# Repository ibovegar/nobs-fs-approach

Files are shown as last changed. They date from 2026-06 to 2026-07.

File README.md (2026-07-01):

# Nobs Approach

A build-it-yourself lever panel for flight simulators: **3 levers** (Flaps, Gear, Parking Brake)
wired to an **Arduino Nano ESP32**. It plugs in over USB and shows up as a standard game controller
(HID gamepad) named **"Nobs Approach"**, recognised directly by MSFS and the Nobs app with no
drivers to install.

All three levers are 3-position (ON-OFF-ON); each lever's two outer positions are reported as two
buttons, for **6 buttons** total.

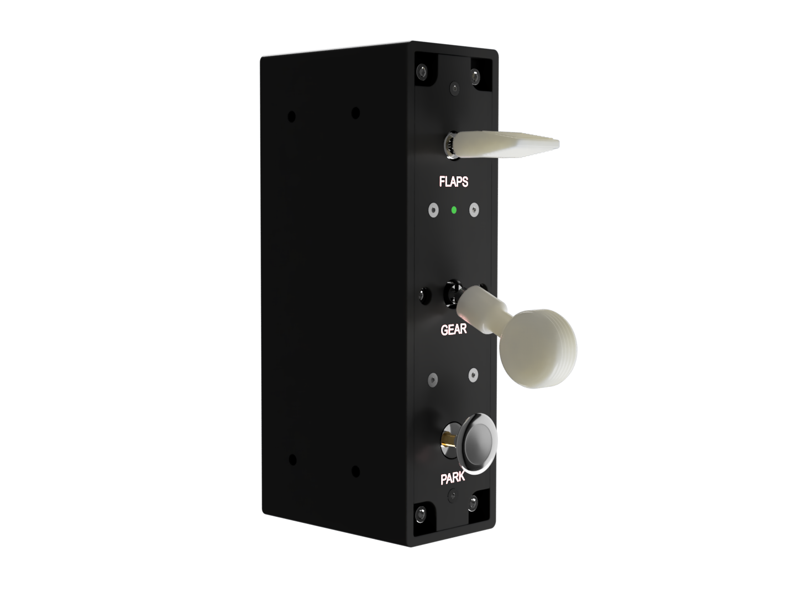
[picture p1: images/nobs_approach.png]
Nobs Approach


## Docs

- **[Which wire goes where](docs/arduino-esp-32-wiring.md)**: the button + pin map. For a visual
  reference alongside it, see the [wiring diagram](docs/wiring-diagram.pdf).
- **[Loading the firmware](firmware/arduino_eps32_nano/README.md)**: first-time flashing and
  re-flashing, step by step.
- **[Setting the device ID & name](docs/board-identity.md)**: how the board names itself, how to
  rename it, and how to run several approach panels at once (each gets its own ID + name).
- **[Bill of materials](docs/bill-of-materials.md)**: parts list.

## Nobs FS Companion App

The [**Nobs FS app**](https://github.com/ibovegar/nobs-fs-app) is the companion application for
communicating with and configuring this panel. It automatically detects the Nobs Approach by its
USB identity (VID `303A` / PID `80F8`), so the right device is selected even when other game
controllers are connected.

Use it to:
* **Verify wiring & test inputs:** watch every lever position register live as you move it, handy
  for confirming the build before binding anything in the sim.
* **Track multiple approach panels:** the Devices page lets you add extra instances of the panel,
  each with its own ID and name (see [Setting the device ID & name](#setting-the-device-id--name-in-brief)
  below), so the app and the sim can tell them apart.

See the app repository for installation and usage details: <https://github.com/ibovegar/nobs-fs-app>

## Setting the device ID & name (in brief)

The board's name and USB product ID aren't compiled in; they're stored on the board, so the same
firmware can be set up as any Nobs profile. Out of the box this is **"Nobs Approach"** (`303A` /
`80F8`). To change it, the configuration app sends a single line over the board's serial port:

```
SET_ID:80F8:Nobs Approach
```

The board saves the new name + ID, replies `OK:80F8:Nobs Approach`, and reboots so it takes effect
(`GET_ID` reads back the current values). For multiple approach panels, give each one the next ID in
the block, e.g. `SET_ID:80F9:Nobs Approach 2`. Full details, including the Windows name-cache
refresh, are in **[docs/board-identity.md](docs/board-identity.md)**.

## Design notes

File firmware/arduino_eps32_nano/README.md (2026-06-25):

# Nobs Approach: Arduino Nano ESP32 Firmware

This is the program (the "firmware") that runs on an **Arduino Nano ESP32** and turns it into a USB
game controller for Microsoft Flight Simulator. Once loaded, the board shows up to your PC and the
Nobs app as **"Nobs Approach"** with **6 buttons**: the 3 levers (Flaps, Gear, Parking Brake), two
buttons each (one per position). Wiring is in
[`docs/arduino-esp-32-wiring.md`](../../docs/arduino-esp-32-wiring.md).

All three levers are **ON-OFF-ON** (3-position): one outer position presses the first button, the
other presses the second, and the center position presses neither.

> 👍 Everything you need is in this folder. You don't edit any Arduino files. Keep
> [`build_opt.h`](./build_opt.h) next to the sketch: the IDE uses it automatically, and the build
> fails on purpose without it. Tested with the Arduino ESP32 board package `2.0.18-arduino.5`.

## One-time setup

1. Install the **Arduino IDE** (free, from arduino.cc).
2. Add the board: **Tools → Board → Boards Manager…**, search **Arduino ESP32 Boards**, click
   **Install** (big download). Then pick **Tools → Board → Arduino ESP32 Boards → Arduino Nano ESP32**.
3. In **Tools**, set **USB Mode → `Normal mode (TinyUSB)`** and **Pin Numbering → `By Arduino pin (default)`**.

> If the board install fails ("platform not installed"), close the IDE, reopen it **as
> administrator**, and try again.

## Flashing the first time

1. Open [`arduino_eps32_nano.ino`](./arduino_eps32_nano.ino) in the Arduino IDE.
2. Plug in the board with a **data** USB cable (not charge-only), straight into the PC.
3. Click **Upload** (the round arrow).

On a fresh board this just works. 🎉 When it's done, the board reconnects as **"Nobs Approach"** and
the app picks it up automatically.

## Re-flashing (after firmware is already on it)

This is **different**, and expected. Once the firmware is running, the board reports a custom USB
ID and no longer auto-enters upload mode, so a normal Upload fails with:

```
No DFU capable USB device available — exit status 74
```

Put the board into **update mode** by hand first:

1. Press the **RESET** button **twice, quickly** (like a mouse double-click, ~0.3–0.5 s apart).
2. You're in update mode when the **green LED breathes slowly in and out and stays there**.
   A quick red→blue→green flash that stops is just a normal reset; try the double-tap again.
3. With the green breathing, click **Upload** right away.
4. When it finishes, press **RESET once** to start the firmware.

> **If upload still can't find the board:** it's almost always the **cable or USB port**; swap to
> a known-good data cable and a different port (this is the most common cause). The double-tap
> timing is the other one; keep trying the rhythm.

## Check it works

- **Nobs app:** the approach panel is detected automatically; move the levers and watch them react.
- **Windows:** press `Win`, type **Set up USB game controllers**, open the device's **Properties**,
  and move the levers to see the 6 buttons react.

## Changing the board's name / ID

The name and product ID aren't compiled in; they're stored on the board, so the same firmware can
become any Nobs profile. Out of the box it's **"Nobs Approach"** (`303A` / `80F8`). The configuration
app changes it over the board's serial port. See
[`docs/board-identity.md`](../../docs/board-identity.md) for how that works and the full profile list.

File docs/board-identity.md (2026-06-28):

# How the Board Names Itself (and How to Rename It)

This page explains, in plain language, how a Nobs board tells your PC who it is, and how you can
change that without re-installing the firmware. You don't need to understand any of this to use the
approach panel; it's here for the curious and for anyone setting up more than one box.

## The short version

- Every Nobs box appears to your PC as a USB game controller with a **name** (like "Nobs Approach")
  and an **ID number** (called a *Product ID*, or **PID**).
- That name and ID are **not baked into the firmware**. The board remembers them in its own memory,
  so the *same* firmware can be set up as a panel, an autopilot, or an approach box.
- Out of the box, this board is **"Nobs Approach"**. You can change it later with the configuration
  app, no re-flashing needed.

## Why each box needs its own name and ID

If you own more than one Nobs box, this matters. Microsoft Flight Simulator keeps a separate set of
button bindings for each controller, but it tells controllers apart by their **ID number**.

If two boxes shared the same ID, the simulator would treat them as the same device and **mix up
their button assignments**. Giving each box its own ID (and a clear name) keeps their controls
neatly separated, so plugging in a second or third box never disturbs the first.

Here are the standard profiles. Each product owns a small **block of IDs** so you can have several
of the same type (see below):

| If the box is a… | It should be named… | ID block |
| :--- | :--- | :--- |
| Panel | Nobs Panel | `80F0`–`80F3` |
| Autopilot | Nobs Autopilot | `80F4`–`80F7` |
| Approach | Nobs Approach | `80F8`–`80FB` |

(They all share the same *vendor* ID, `303A`; that part never changes.)

## Running several of the same type

You can use more than one of the same module, say two approach panels, at the same time. The
catch is they must **not** look identical to the PC, or the simulator mixes up their bindings. So
each one gets its own ID and name from its product's block:

| | Name | ID |
| :-- | :-- | :-- |
| 1st approach | Nobs Approach | `80F8` |
| 2nd approach | Nobs Approach 2 | `80F9` |
| 3rd approach | Nobs Approach 3 | `80FA` |

The first one keeps the plain name and the block's first ID (its out-of-box default). For each
extra one, give it the next ID and a numbered name with the rename step below: e.g. send
`SET_ID:80F9:Nobs Approach 2` to the second one. In the Nobs app, open **Devices** and press **+**
on that product to start tracking the extra module. The simulator then sees "Nobs Approach" and
"Nobs Approach 2" as two separate controllers with independent bindings.

## How to rename a board

The configuration app does this for you. Behind the scenes it just sends the board one short line of
text over its connection, for example:

```
SET_ID:80F8:Nobs Approach
```

That reads as: *"Set your ID to `80F8` and your name to `Nobs Approach`."* The board then:

1. **Saves** the new name and ID into its own memory.
2. **Confirms** it received them.
3. **Restarts itself**, and comes back wearing the new name.

That restart is normal and only takes a second. The reason it's needed: a board can only announce
its identity to the PC at the moment it powers on, so it has to reboot for a new name to take effect.

> 💡 To check what a board is currently called, the app can ask it with `GET_ID`, and the board
> replies with its stored name and ID. The board also announces its name and ID on its own, the
> moment the app connects — so the app doesn't even need to ask.

## If Windows still shows the old name

Windows likes to remember names, so occasionally after a rename it'll keep showing the **old** one
in its game-controller list or in the simulator. If that happens, nudge it to take a fresh look:

1. Leave the board plugged in.
2. Right-click the **Start** button → open **Device Manager**.
3. Open the **Human Interface Devices** group.
4. Right-click your controller → **Uninstall device**.
5. Unplug the USB cable, wait a couple of seconds, and plug it back in.

Windows will then read the board's name again from scratch and show the updated one.

## Related pages

- [Which wire goes where](./arduino-esp-32-wiring.md): the button and pin map.
- [Loading the firmware](../firmware/arduino_eps32_nano/README.md): step-by-step setup, including
  the more technical details of how the identity is stored.

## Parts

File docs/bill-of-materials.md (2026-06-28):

# Bill of Materials (Shopping List)

This is the full shopping list for building one Nobs Approach panel: every part you need, from the
electronics to the screws. The "Manufacturer / Part Number" column lists the exact parts we used,
linked to their Mouser listing, so you can search for them or find equivalents.

A few friendly notes before you start buying:

- **Exact parts aren't mandatory.** Most components can be swapped for similar parts you like or
  already have. The part numbers here are just what's known to work.
- **The enclosure and lever parts are 3D printed**: you print them yourself from the files in the
  `models/` folder, or have a print service make them.
- Quantities are for **one** panel.

## Core Electronics & Switches

| Item # | Qty | Component Description | Manufacturer / Part Number | Purpose / Application |
| :--- | :--- | :--- | :--- | :--- |
| **1.1** | 1 | Arduino Nano ESP32 (with headers) | [Arduino / ABX00083](https://no.mouser.com/ProductDetail/Arduino/ABX00083) | Main microcontroller (ESP32-S3, USB HID, VID 0x303A / PID 0x80F8) |
| **1.2** | 1 | SPDT Toggle Switch, Locking Lever, On-On (2-position), 15 A @ 125 VAC | [NKK Switches / S2AL](https://no.mouser.com/ProductDetail/NKK-Switches/S2AL?qs=EIJ16CYJdOsFNpXA4HNUoQ%3D%3D) | Gear lever, under `models/gear_lever.step` |
| **1.3** | 1 | SPDT Toggle Switch, Momentary (On)-Off-(On), 15 A @ 125 VAC | [Apem / 637H-2](https://no.mouser.com/ProductDetail/Apem/637H-2?qs=sGAEpiMZZMtFyPk3yBMYYM4hYjBerRHjpwkY%2FkVx7u8%3D) | Flaps lever, under `models/flaps_lever_top.step` + `flaps_lever_bottom.step` |
| **1.4** | 1 | SPDT Push-Pull Switch, On-On (2-position), Marine Grade, 10 A @ 12 VDC | [Cole Hersee / M-630](https://no.mouser.com/ProductDetail/Cole-Hersee/M-630?qs=lYH8mLnNY3r10KRvj4ytOg%3D%3D) | Parking brake lever, under `models/gear_lever.step` (shared shape) |
| **1.5** | 1 | Stripboard, 50 × 80 mm | [BusBoard Prototype Systems / ST1](https://no.mouser.com/ProductDetail/BusBoard-Prototype-Systems/ST1) | Controller board carrier for the Arduino, pin headers, and terminal block |
| **1.6** | 2 | Female Pin Header Socket, 26-position, 2.54 mm pitch | [3M Electronic Solutions Division / 929850-01-26-RA](https://no.mouser.com/ProductDetail/3M-Electronic-Solutions-Division/929850-01-26-RA) | Sockets soldered to the stripboard to seat the Arduino Nano ESP32 |
| **1.7** | 1 | Fixed Terminal Block, 6-position, 2.54 mm pitch | [GCT / TBC05-06-1-G-G](https://no.mouser.com/ProductDetail/GCT/TBC05-06-1-G-G) | Screw-down wiring for the 6 lever signal terminals (Flaps/Gear/Brake Pin 1 + Pin 3); the lever ground returns bus directly to the stripboard's GND rail |
| **1.8** | 1 | 3 mm Green LED, Diffused, 2.2 V | [Lumex / SSL-LX30FT4GD](https://no.mouser.com/ProductDetail/Lumex/SSL-LX30FT4GD?qs=7jmq9uQgtYG4HR2h%252BlgbMw%3D%3D) | Status indicator (blinks while booting/waiting for USB enumeration, steady once connected) — wired to D4 |
| **1.9** | 1 | 120 Ω Resistor, 1/4 W, ±1%, Metal Film | [KOA Speer / MFS1/4DCT52R1200F](https://no.mouser.com/ProductDetail/KOA-Speer/MFS1-4DCT52R1200F?qs=ddCg%252BR5cWn20oJHZLuYO%2FQ%3D%3D) | Current-limiting resistor for the status LED |

## Structural & Enclosure Hardware

| Item # | Qty | Component Description | Manufacturer / Part Number | Purpose / Application |
| :--- | :--- | :--- | :--- | :--- |
| **2.1** | 1 | Enclosure Top | 3D Printed (`models/enclosure_top.step`) | Main upper housing shell |
| **2.2** | 1 | Enclosure Bottom | 3D Printed (`models/enclosure_bottom.step`) | Main lower housing base, carries the controller board |
| **2.3** | 1 | Mounting Plate | 3D Printed (`models/nobs_approach_mounting_plate.step`) | Carries the 3 levers |
| **2.4** | 1 | Front Plate | 3D Printed (`models/nobs_approach_frontpanel.step`) | Visual faceplate with lever labels |
| **2.5** | 1 | Flaps Lever, Top | 3D Printed (`models/flaps_lever_top.step`) | Upper half of the Flaps lever assembly |
| **2.6** | 1 | Flaps Lever, Bottom | 3D Printed (`models/flaps_lever_bottom.step`) | Lower half of the Flaps lever assembly |
| **2.7** | 2 | Gear / Parking Brake Lever | 3D Printed (`models/gear_lever.step`) | Shared lever shape, printed once for Gear and once for Parking Brake |
| **2.8** | 10 | M4 Heat-Set Insert | [SI (PennEngineering) / IUTB-M4](https://no.mouser.com/ProductDetail/SI/IUTB-M4) | Threaded anchors moulded into the enclosure top/bottom |
| **2.9** | 10 | M3 Heat-Set Insert | [SI (PennEngineering) / IUTB-M3](https://no.mouser.com/ProductDetail/SI/IUTB-M3) | Threaded anchors moulded into the mounting plate and front plate |
| **2.10** | 4 | M4 × 0.7, 30 mm Socket-Head Screw | — | Clamps the enclosure top and bottom halves together |
| **2.11** | 6 | M4 × 0.7, 10 mm Socket-Head Screw | — | Fastens the mounting plate to the rear of the enclosure bottom |
| **2.12** | 4 | M3 × 0.5, 8 mm Pan-Head Screw | — | Fastens the controller board to its standoffs in the enclosure bottom |
| **2.13** | 6 | M3 × 0.5, 8 mm Countersunk Screw | — | Fastens the front plate to the mounting plate, and the assembly to the enclosure |

## Connectors & Wiring

| Item # | Qty | Component Description | Manufacturer / Part Number | Purpose / Application |
| :--- | :--- | :--- | :--- | :--- |
| **3.1** | 1 | USB-C to USB-A Cable, 1.5 m to 2 m, data-sync capable | — | Connects the Arduino Nano ESP32 to your PC |
| **3.2** | 1 | Heat Shrink Tubing Assortment Pack, 1.5 mm to 3.5 mm diameters | — | Insulates soldered connections on the lever terminals |

> **A note on the fastener counts above:** `enclosure_top.step`/`enclosure_bottom.step` in this
> project are geometrically identical to the panel project's, and the mounting-plate/front-plate
> *joining* holes (the ones that bolt the plates together and to the enclosure) match too — only
> the switch/lever cutouts differ, which is expected since this panel has 3 levers instead of 8
> switches. So items 2.8–2.13 are carried over directly from the panel BOM. Still worth a quick
> visual check against the printed parts before ordering, since this wasn't measured by hand.

## Project Costs

Rough cost estimate for a single panel, in USD. These are ballpark figures only, actual prices
vary significantly by supplier, region, and quantity, and **exclude shipping and taxes**. Several
items (heat-set inserts, screws) are sold in multi-build packs, so the per-build cost is lower if
you build more than one or already have them on hand.

| Category | Items | Estimated Cost |
| :--- | :--- | ---: |
| Microcontroller | Arduino Nano ESP32 (genuine; clones are cheaper) | $20 – $28 |
| Levers (switches) | NKK S2AL toggle + Apem 637H-2 + Cole Hersee M-630 | $30 – $55 |
| Board & connectors | Stripboard, 2 × pin headers, terminal block, status LED + resistor | $10 – $15 |
| Fasteners | Heat-set inserts (20) and M3/M4 screws (20) | $10 – $18 |
| Enclosure (3D printed) | Filament for top, bottom, mounting plate, front plate, and 3 levers | $5 – $15 |
| Connectors & wiring | USB-C cable, heat-shrink tubing pack | $8 – $15 |
| **Total** | | **≈ $83 – $146** |

> **Notes:**
> * The **enclosure** assumes you print the parts yourself (filament cost only). Ordering them
>   from a print service will add roughly $20 – $50.
> * This estimate doesn't include hookup wire, since it's usually bought once in bulk and reused
>   across builds.
> * Bulk/pack purchasing of the inserts, screws, and heat-shrink tubing spreads their cost across
>   multiple builds, lowering the effective per-panel total.

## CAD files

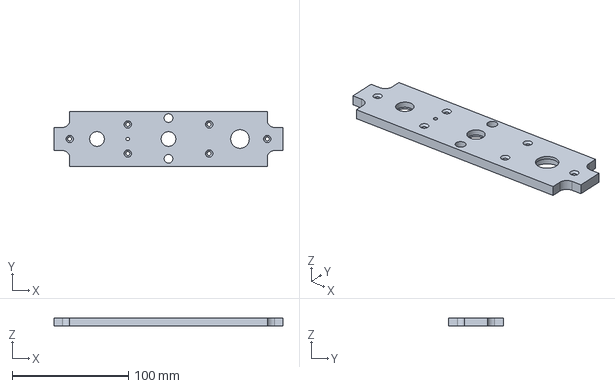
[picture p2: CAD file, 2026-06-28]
models/nobs_approach_frontpanel.step
197.0 x 47.0 x 7.00 mm

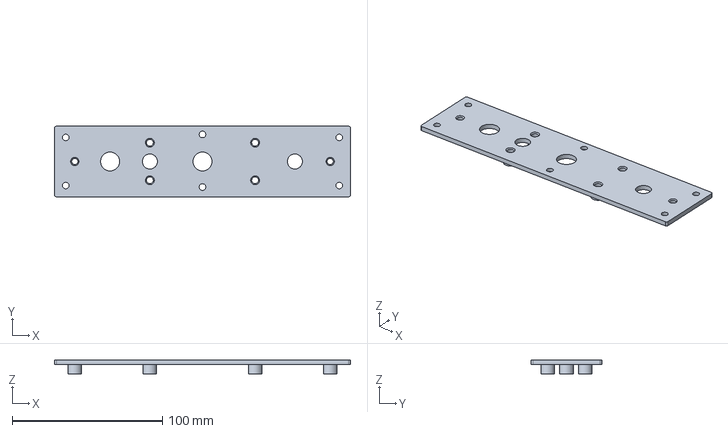
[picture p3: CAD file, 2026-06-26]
models/nobs_approach_mounting_plate.step
197.0 x 47.0 x 9.00 mm

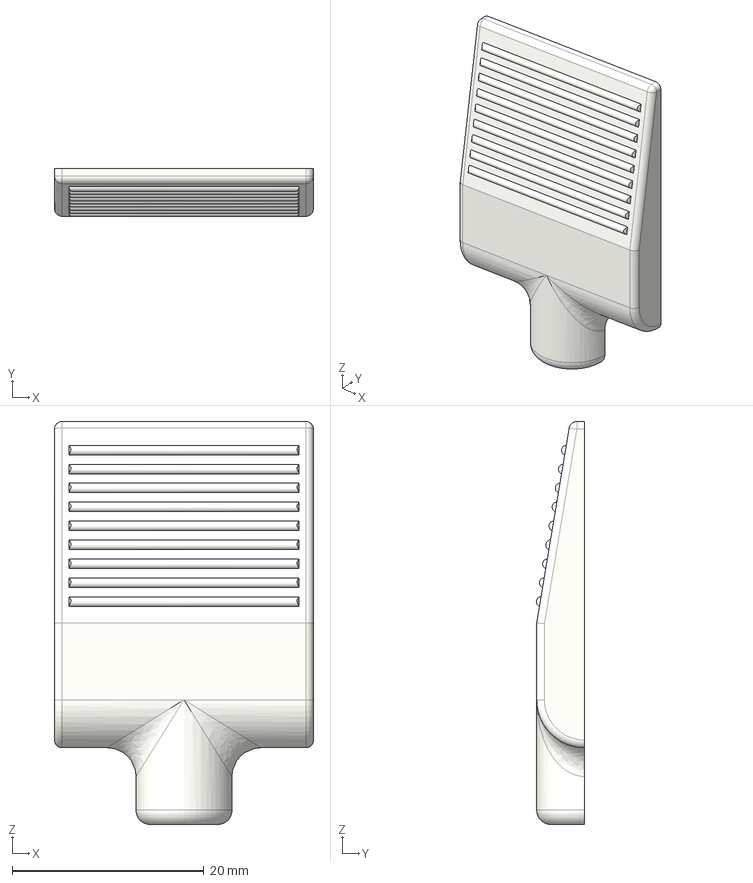
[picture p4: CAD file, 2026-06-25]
models/flaps_lever_bottom.step
27.0 x 5.04 x 42.0 mm

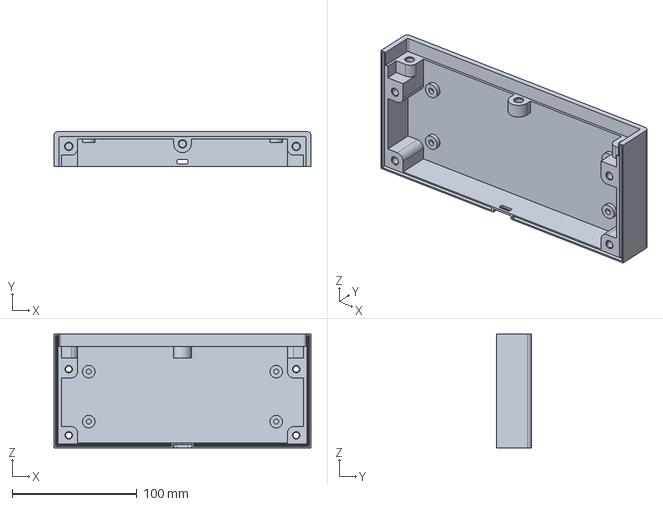
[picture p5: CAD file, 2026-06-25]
models/enclosure_top.step
205.6 x 27.8 x 91.0 mm

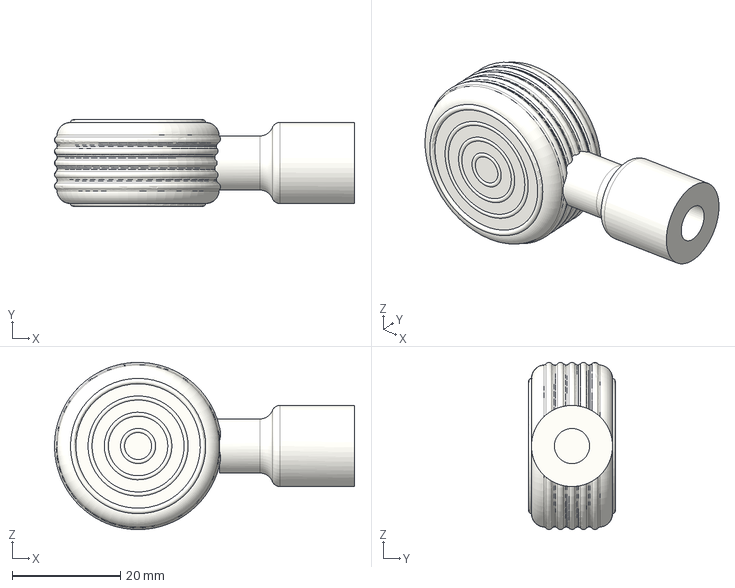
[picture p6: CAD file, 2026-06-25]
models/gear_lever.step
55.5 x 16.0 x 30.9 mm

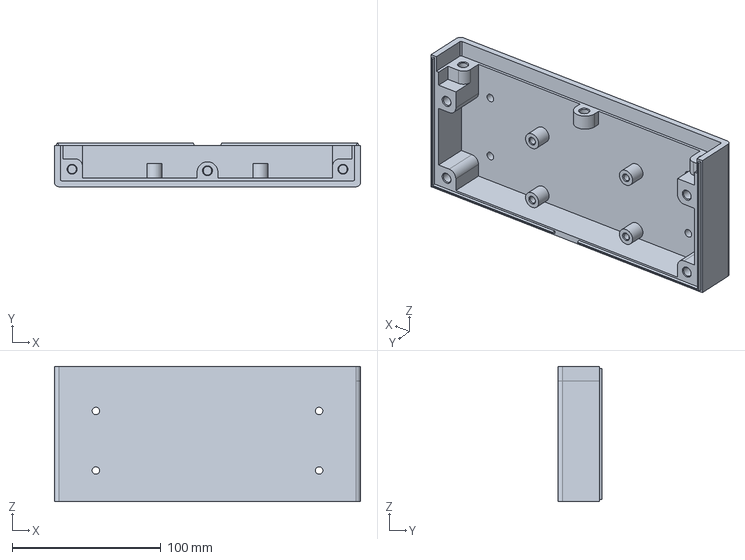
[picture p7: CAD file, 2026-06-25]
models/enclosure_bottom.step
205.6 x 29.3 x 91.0 mm

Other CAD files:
models/flaps_lever_top.step

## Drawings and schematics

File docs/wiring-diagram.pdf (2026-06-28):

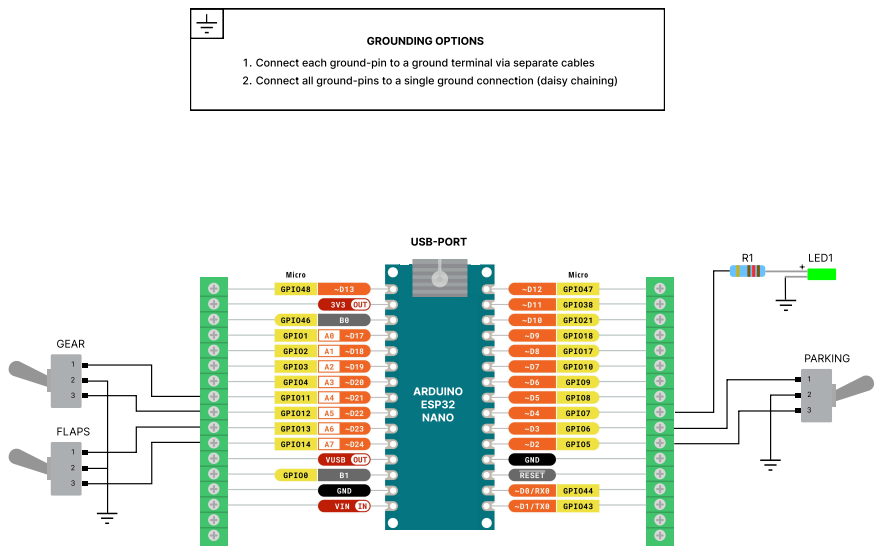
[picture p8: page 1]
GROUNDING OPTIONS; USB-PORT; LED1; GEAR; ARDUINO; ESP32 NANO; PARKING; FLAPS

Connect each ground-pin to a ground terminal via separate cables
Connect all ground-pins to a single ground connection (daisy chaining)

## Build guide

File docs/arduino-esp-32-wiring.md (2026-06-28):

# Wiring Map: Which Wire Goes Where

This table tells you which pin on the board each wire connects to, for the **Arduino Nano ESP32**.

This box has **3 levers** (Flaps, Gear, and Parking Brake), and they are all **ON-OFF-ON**
(3-position, with the center position doing nothing). Each lever has three terminals: the two outer
terminals (pin 1 and pin 3) each go to a signal pin, and the center terminal (pin 2) goes to
**GND**. There's also a **status LED**, which is part of the build, not optional.

**How to read a row:** find the lever (e.g. "Flaps"), look at which terminal it is ("Pin 1"), then
run a wire from that terminal to the pin listed in the board's column. Pin names like `A6` or `D3`
are printed on the board itself. Every lever's center terminal (pin 2) connects to **GND**
(ground), see the last row.

The "Virtual HID Button" column is just for reference: it's the button number the sim sees when you
move that lever into that position. You don't wire anything for it.

> 💡 Each lever terminal has one wire to its signal pin (from this table) and the center terminal
> wires to **GND**. No resistors or extra parts needed; the firmware handles that.

| Component Group | Component Label | Hardware Connection | Arduino Nano ESP32 Pin | Virtual HID Button | Action Type |
| :--- | :--- | :--- | :--- | :--- | :--- |
| **Flaps** (ON-OFF-ON) | Flaps lever | Pin 1 Terminal | **A6** | Button 2 | Position 2 |
| | Flaps lever | Pin 3 Terminal | **A7** | Button 1 | Position 1 |
| **Gear** (ON-OFF-ON) | Gear lever | Pin 1 Terminal | **A4** | Button 3 | Position 1 |
| | Gear lever | Pin 3 Terminal | **A5** | Button 4 | Position 2 |
| **Parking Brake** (ON-OFF-ON) | Parking brake lever | Pin 1 Terminal | **D3** | Button 5 | Position 1 |
| | Parking brake lever | Pin 3 Terminal | **D2** | Button 6 | Position 2 |
| **Ground Loop** | All levers | Pin 2 / Center Terminals | **GND** | *None* | System Ground |
| **Status LED** | Status LED | Anode, via 120 Ω resistor | **D4** | *None* | Boot/Connect Status |
| | Status LED | Cathode | **GND** | *None* | Boot/Connect Status |

> 💡 **Status LED:** wired with a 120 Ω current-limiting resistor (see
> [bill-of-materials.md](bill-of-materials.md)) from **D4** to **GND**. It blinks while the board
> is booting/waiting for USB enumeration, and lights steady once the host PC has enumerated it.

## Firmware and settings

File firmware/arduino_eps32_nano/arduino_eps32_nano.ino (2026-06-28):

// Nobs Approach — Arduino Nano ESP32 (ESP32-S3) USB HID gamepad firmware.
//
// A switch-only sibling of the Nobs Panel build, ported to the ESP32-S3's native
// USB. Exposes 6 buttons in the exact order the nobs-fs app expects:
//   buttons 0..5 → 3 levers × 2 outer terminals each
//                  (Flaps Pin3, Flaps Pin1, Gear Pin1, Gear Pin3, Brake Pin1, Brake Pin3)
// Flaps is wired Pin1→Button2/Pin3→Button1 (inverted from the other two levers) so the
// lever's physical up/down sense matches the sim without re-wiring it.
// All three levers are ON-OFF-ON (3-position): the center position grounds neither
// terminal, so both of that lever's buttons read released.
// See docs/arduino-esp-32-wiring.md for the full button + pin table.
//
// There are no encoders, so this sketch has no quadrature decoding, no acceleration,
// and no EEPROM acceleration store. Every input is a plain switch reported as a held
// button level.
//
// The HID report also doubles as a Feature report (GET_REPORT(Feature)) so a host can
// read the resting lever positions the instant it opens the device, and loop() resends
// the Input report on a 250 ms heartbeat so a host that opens the device later (missing
// the one-shot initial report) still re-syncs without the user touching a lever.
//
// ── Arduino IDE Tools settings (required) ─────────────────────────────────────
//   Board:        "Arduino Nano ESP32"
//   USB Mode:     "Normal mode (TinyUSB)"     ← the default; needed for custom HID
//   Pin Numbers:  "By Arduino pin (default)"   so D0/A0… match the wiring doc
// No other Tools changes and NO edits to the installed Arduino core are needed — the
// whole USB-identity fix lives in this repo (this sketch + build_opt.h beside it).
//
// ── USB identity: dynamic, stored in NVS (Preferences) ────────────────────────
// The device enumerates with VID 0x303A (Espressif's vendor ID) and a PID + product
// name that are *configurable at runtime*. Each Nobs box gets its own PID so MSFS
// can't mirror/overwrite control bindings across boxes. Out of the box it defaults to
// PID 0x80F8 / "Nobs Approach" (matches the `approach` entry in the app's device
// registry, src/panel/panel.ts).
//
// The PID and name live in flash via the native Preferences library (NVS). On boot
// the firmware reads them *before* USB.begin() and applies them to the descriptor.
// The configuration/diagnostic app can change them over the USB CDC serial port:
//
//   "SET_ID:<pidHex>:<name>\n"  store PID (hex, e.g. 80F8) + product name to NVS,
//                               then soft-reboot so the new identity takes effect
//   "GET_ID\n"                  reply "ID:<pidHex>:<name>" with the stored values
//
// After SET_ID the firmware replies "OK:<pidHex>:<name>", flushes, and calls
// ESP.restart(); the host re-enumerates the device under its new profile. (Identity
// can't change live mid-session because the USB stack is brought up once at boot.)
//
// The firmware also pushes its identity unprompted, as "BOOT:<pidHex>:<name>\n", the
// moment a host opens the CDC port (DTR asserted) — so the nobs-fs app learns which
// box it's talking to as soon as it connects, with no GET_ID round trip required. This
// fires again on every reconnect (including the re-enumeration after a SET_ID reboot).
//
// This NVS-at-boot scheme works because the Nano ESP32 normally forces "USB CDC On
// Boot" and "DFU On Boot" on, which would make the core bring USB up at boot (before
// setup()), freezing the descriptor with the stock 0x2341/0x0070 identity. The
// build_opt.h file next to this sketch overrides both to 0 (it is appended to every
// compile, including the core's), so the boot-time USB.begin() is skipped and our
// runtime identity wins. With CDC-on-boot off, the core's `Serial` is the hardware
// UART, so the app's config port is our own USB CDC interface (USBSerial below).
//
// Re-flashing: the running firmware reports a custom PID (and, with DFU-on-boot off, no
// DFU runtime interface), so the IDE can't auto-enter the bootloader. Double-tap the
// RESET button (RGB LED pulses) before uploading. See this folder's README.md.

#include "USB.h"
#include "USBHID.h"
#include "USBCDC.h"
#include <Preferences.h>

#if ARDUINO_USB_MODE
#error "Set Tools > USB Mode to 'Normal mode (TinyUSB)'. Custom HID needs the TinyUSB stack."
#endif
#if ARDUINO_USB_CDC_ON_BOOT
#error "build_opt.h is not taking effect: ARDUINO_USB_CDC_ON_BOOT must be 0. Make sure build_opt.h sits next to this .ino (it disables CDC/DFU-on-boot so the runtime USB identity works)."
#endif

// ── Custom HID gamepad: 6 buttons, no axes ────────────────────────────────────
// 6 1-bit buttons + 2 bits of padding pack into a flat 1-byte report. The same 6 bits
// are also declared as a Feature report so a host can pull the current lever positions
// on demand (GET_REPORT(Feature)) the moment it opens the device — see _onGetFeature.
// The Feature item re-declares its own Report Count (the Input padding above changed
// the global count) and gets its own 2 padding bits so it, too, is a whole byte.
static const uint8_t HID_REPORT_DESCRIPTOR[] = {
  0x05, 0x01,        // Usage Page (Generic Desktop)
  0x09, 0x05,        // Usage (Game Pad)
  0xA1, 0x01,        // Collection (Application)
  0x05, 0x09,        //   Usage Page (Button)
  0x19, 0x01,        //   Usage Minimum (Button 1)
  0x29, 0x06,        //   Usage Maximum (Button 6)
  0x15, 0x00,        //   Logical Minimum (0)
  0x25, 0x01,        //   Logical Maximum (1)
  0x75, 0x01,        //   Report Size (1)
  0x95, 0x06,        //   Report Count (6)
  0x81, 0x02,        //   Input (Data,Var,Abs)
  0x95, 0x02,        //   Report Count (2)   — padding to a whole byte
  0x81, 0x03,        //   Input (Const,Var,Abs)
  0x19, 0x01,        //   Usage Minimum (Button 1)   — re-declared for the Feature item
  0x29, 0x06,        //   Usage Maximum (Button 6)
  0x95, 0x06,        //   Report Count (6)           — re-declared (padding above changed it)
  0xB1, 0x02,        //   Feature (Data,Var,Abs)     — same 6 bits, host-readable on demand
  0x95, 0x02,        //   Report Count (2)           — padding so the Feature item is a whole byte too
  0xB1, 0x03,        //   Feature (Const,Var,Abs)
  0xC0               // End Collection
};

class NobsGamepad : public USBHIDDevice {
public:
  NobsGamepad() { HID.addDevice(this, sizeof(HID_REPORT_DESCRIPTOR)); }

  void begin() { HID.begin(); }

  // Set/clear one button bit in the pending report (mirrors Joystick.setButton).
  void setButton(uint8_t index, uint8_t value) {
    if (index >= 6) return;
    uint8_t mask = 1 << index;
    if (value) report[0] |= mask;
    else       report[0] &= ~mask;
  }

  // One USB report carrying every button change since the last call (mirrors
  // Joystick.sendState). Only transmitted when something actually changed — HID
  // hosts track button state edge-to-edge, so re-sending identical reports just
  // adds USB traffic and risks blocking the loop.
  void sendState() {
    if (report[0] == lastSent) return;
    if (HID.SendReport(0, report, sizeof(report))) {
      lastSent = report[0];
    }
  }

  // Re-publish the current report even when nothing changed. The initial report is
  // only emitted once (on the first change after boot), so a host that opens the
  // device later misses it and can't know the resting lever positions until the user
  // moves something. loop() calls this on a slow heartbeat so any host re-syncs the
  // true state within the heartbeat interval.
  void resend() {
    if (HID.SendReport(0, report, sizeof(report))) {
      lastSent = report[0];
    }
  }

  // USBHIDDevice: hand the descriptor to the core during enumeration.
  uint16_t _onGetDescriptor(uint8_t* buffer) override {
    memcpy(buffer, HID_REPORT_DESCRIPTOR, sizeof(HID_REPORT_DESCRIPTOR));
    return sizeof(HID_REPORT_DESCRIPTOR);
  }

  // Answer GET_REPORT(Feature) with the current button state. This lets a host read
  // the resting lever positions the instant it opens the device, instead of waiting
  // for the heartbeat or a user actuation. (The ESP32 USB stack routes feature
  // get-reports here but STALLs input get-reports, so on-demand state is exposed as a
  // Feature report mirroring the Input report's 6 button bits.)
  uint16_t _onGetFeature(uint8_t report_id, uint8_t* buffer, uint16_t len) override {
    (void)report_id; // single unnumbered report
    if (len < sizeof(report)) return 0;
    memcpy(buffer, report, sizeof(report));
    return sizeof(report);
  }

private:
  USBHID  HID;
  uint8_t report[1] = { 0 };
  uint8_t lastSent  = 0xFF; // force the first real report out
};

NobsGamepad Joystick;

// USB CDC config port. With CDC-on-boot disabled (via build_opt.h) the core's `Serial`
// is the hardware UART, so we expose our own USB CDC interface for the config app.
// Like USBHID, USBCDC registers its interface in its constructor (static init), so it
// is in place before USB.begin() builds the composite descriptor in setup().
USBCDC USBSerial;

// ── Dynamic USB identity (NVS via Preferences) ────────────────────────────────
// VID is fixed (Espressif's vendor ID); PID + product name are stored in flash and
// host-configurable. Defaults are the approach profile; an unconfigured chip uses them.
// NB: named NOBS_USB_VID, not USB_VID — the core's pins_arduino.h #defines USB_VID.
const uint16_t NOBS_USB_VID    = 0x303A;
const uint16_t DEFAULT_PID     = 0x80F8;
const char*    DEFAULT_NAME    = "Nobs Approach";
const char*    NVS_NAMESPACE   = "nobs";
const char*    NVS_KEY_PID     = "pid";
const char*    NVS_KEY_NAME    = "name";

Preferences prefs;
uint16_t     usbPid;     // active PID (kept alive for the whole session)
String       usbName;    // active product name (c_str() must outlive USB.begin())

void loadIdentity() {
  prefs.begin(NVS_NAMESPACE, true); // read-only
  usbPid  = prefs.getUShort(NVS_KEY_PID, DEFAULT_PID);
  usbName = prefs.getString(NVS_KEY_NAME, DEFAULT_NAME);
  prefs.end();
}

void storeIdentity(uint16_t pid, const String& name) {
  prefs.begin(NVS_NAMESPACE, false); // read-write
  prefs.putUShort(NVS_KEY_PID, pid);
  prefs.putString(NVS_KEY_NAME, name);
  prefs.end();
}

// ── USB string descriptors: name the interfaces after the product ─────────────
// The core hardcodes the HID/CDC *interface* strings to "TinyUSB HID"/"TinyUSB CDC".
// For a composite device (HID + CDC) Windows and MSFS show that interface string as
// the controller's name — so without this the box shows up as "TinyUSB HID" even
// though iProduct is "Nobs Approach". tud_descriptor_string_cb is weak in the core,
// so defining it here replaces it (no core edit needed) and points every interface
// string at the product name. Index map: 0=language, 1=manufacturer, 2=product,
// 3=serial (from the chip MAC, stable per board), 4+=interface strings → product.
extern "C" const uint16_t* tud_descriptor_string_cb(uint8_t index, uint16_t langid) {
  (void)langid;
  static uint16_t desc[40];

  if (index == 0) {
    desc[1] = 0x0409; // English (United States)
    desc[0] = (uint16_t)((3 << 8) | (2 * 1 + 2));
    return desc;
  }
  // Beyond our real strings (1..3 + a handful of interface strings). Returning NULL
  // mirrors the core and lets Windows' MS-OS probe at index 0xEE fail cleanly.
  if (index >= 16) return NULL;

  char serial[16];
  const char* str;
  switch (index) {
    case 1: str = "Arduino"; break;       // manufacturer (matches USB.manufacturerName)
    case 2: str = usbName.c_str(); break; // product (iProduct)
    case 3:                               // serial — stable per board
      snprintf(serial, sizeof(serial), "%012llX", (unsigned long long)ESP.getEfuseMac());
      str = serial;
      break;
    default: str = usbName.c_str(); break; // HID/CDC/config interface strings
  }

  uint8_t chr_count = strlen(str);
  if (chr_count > 38) chr_count = 38; // desc holds 39 UTF-16 chars + the header word
  for (uint8_t i = 0; i < chr_count; i++) desc[1 + i] = str[i];
  desc[0] = (uint16_t)((3 << 8) | (2 * chr_count + 2));
  return desc;
}

// ── Pin assignments (Arduino Nano ESP32 labels — see arduino-esp-32-wiring.md) ─
// In HID button order: button i is driven by leverPin[i]. Each lever contributes two
// consecutive buttons (its Pin 1 and Pin 3 terminals); the center terminal is GND.
//
//   index  HID button  lever / terminal      pin
//   0      Button 1     Flaps Pin 3           A7
//   1      Button 2     Flaps Pin 1           A6
//   2      Button 3     Gear Pin 1            A4
//   3      Button 4     Gear Pin 3            A5
//   4      Button 5     Parking brake Pin 1   D3
//   5      Button 6     Parking brake Pin 3   D2
const uint8_t leverPin[6] = { A7, A6, A4, A5, D3, D2 };

// NOTE: every pin above is driven with INPUT_PULLUP, so the closed-to-GND wiring
// reads LOW = pressed. All of these GPIOs support the ESP32-S3 internal pull-up;
// if a future revision moves a signal onto a pull-up-less pad, add an external
// 10 kΩ pull-up to 3V3 there.

// ── Status LED (D4) ────────────────────────────────────────────────────────────
// Blinks while booting/waiting for USB enumeration, steady once enumerated. D4 also
// doubles as DSR (a USB CDC modem-control signal), but this sketch never drives DSR,
// so the pin is free for plain GPIO use.
const uint8_t STATUS_LED_PIN = D4;

// ── Host serial config ───────────────────────────────────────────────────────
// Line protocol over the USB CDC port (see header). SET_ID persists a new identity
// to NVS and reboots; GET_ID reports the current one; BOOT is pushed unprompted on
// connect (see onCdcEvent below) and needs no host request.
char    cmdBuf[64];
uint8_t cmdLen = 0;

void printIdentity(const char* prefix) {
  char pidHex[5];
  snprintf(pidHex, sizeof(pidHex), "%04X", usbPid);
  USBSerial.print(prefix);
  USBSerial.print(':');
  USBSerial.print(pidHex);
  USBSerial.print(':');
  USBSerial.println(usbName);
}

// ── Unprompted identity push on connect ───────────────────────────────────────
// The CDC line-state event fires whenever the host opens/closes the port (DTR), which
// on Windows tracks the nobs-fs app actually connecting — not just USB enumeration.
// The event runs on the USB/event task, so it only sets a flag here; loop() does the
// actual send. announceIdentity starts true so the very first loop() iteration (in case
// a host is already attached, e.g. after a SET_ID reboot) also pushes one.
volatile bool announceIdentity = true;

void onCdcEvent(void* arg, esp_event_base_t base, int32_t id, void* eventData) {
  (void)arg;
  (void)base;
  if (id != ARDUINO_USB_CDC_LINE_STATE_EVENT) return;
  auto* data = (arduino_usb_cdc_event_data_t*)eventData;
  if (data->line_state.dtr) announceIdentity = true;
}

// ── USB enumeration tracking (for the status LED) ─────────────────────────────
// This device is read purely over HID for normal use — the CDC port (and its DTR
// signal above) is only ever opened for one-off config, so it can't tell us whether
// the flight-sim app is actually using the device. The best available signal is USB
// enumeration itself: ARDUINO_USB_STARTED_EVENT fires once the host finishes
// recognizing the composite device (tud_mount_cb), ARDUINO_USB_STOPPED_EVENT if it's
// unplugged or the bus drops (tud_umount_cb). So "connected" here means "enumerated
// by a host", not "the app has it open" — there's no such signal for a plain HID
// gamepad with no application-level handshake.
volatile bool hostConnected = false;

void onUsbEvent(void* arg, esp_event_base_t base, int32_t id, void* eventData) {
  (void)arg;
  (void)base;
  (void)eventData;
  if (id == ARDUINO_USB_STARTED_EVENT) hostConnected = true;
  else if (id == ARDUINO_USB_STOPPED_EVENT) hostConnected = false;
}

// Blink while booting/waiting for USB enumeration; steady once enumerated
// (hostConnected, set from the USB started/stopped events above). Non-blocking so it
// never stalls loop().
void updateStatusLed() {
  if (hostConnected) {
    digitalWrite(STATUS_LED_PIN, HIGH);
    return;
  }
  static uint32_t lastToggle = 0;
  static bool     ledOn      = false;
  uint32_t now = millis();
  if (now - lastToggle >= 150) {
    lastToggle = now;
    ledOn = !ledOn;
    digitalWrite(STATUS_LED_PIN, ledOn);
  }
}

void applyConfigCommand(const char* s) {
  if (strcmp(s, "GET_ID") == 0) {
    printIdentity("ID");
    return;
  }
  if (strncmp(s, "SET_ID:", 7) != 0) return;

  const char* p     = s + 7;          // "<pidHex>:<name>"
  const char* colon = strchr(p, ':');
  if (!colon || colon == p) return;   // need a PID and a separator

  char pidStr[8] = { 0 };
  size_t n = colon - p;
  if (n >= sizeof(pidStr)) return;
  memcpy(pidStr, p, n);
  uint16_t pid = (uint16_t)strtol(pidStr, nullptr, 16);

  String name = colon + 1;            // everything after the second ':'
  name.trim();
  if (name.length() == 0) return;

  storeIdentity(pid, name);
  // Reflect the just-stored values, confirm, then reboot so USB re-enumerates.
  usbPid  = pid;
  usbName = name;
  printIdentity("OK");
  USBSerial.flush();
  delay(50);                          // let the CDC packet drain before reset
  ESP.restart();
}

void handleSerialConfig() {
  while (USBSerial.available()) {
    char c = USBSerial.read();
    if (c == '\n' || c == '\r') {
      cmdBuf[cmdLen] = '\0';
      if (cmdLen > 0) applyConfigCommand(cmdBuf);
      cmdLen = 0;
    } else if (cmdLen < sizeof(cmdBuf) - 1) {
      cmdBuf[cmdLen++] = c;
    } else {
      cmdLen = 0; // overlong line (no newline) — drop it and resync
    }
  }
}

void setup() {
  for (uint8_t i = 0; i < 6; i++) {
    pinMode(leverPin[i], INPUT_PULLUP);
  }
  pinMode(STATUS_LED_PIN, OUTPUT);

  // Load the saved identity (PID + name) from NVS, falling back to the approach
  // defaults on a fresh chip.
  loadIdentity();

  // USB identity — set BEFORE USB.begin() so the descriptor is built with the stored
  // VID/PID/name. This works because build_opt.h disabled CDC/DFU-on-boot, so USB has
  // NOT been started yet.
  USB.VID(NOBS_USB_VID);
  USB.PID(usbPid);
  USB.productName(usbName.c_str());
  USB.manufacturerName("Arduino");

  Joystick.begin();        // create the HID report semaphores/mutex
  USBSerial.onEvent(ARDUINO_USB_CDC_LINE_STATE_EVENT, onCdcEvent); // detect host connect
  USB.onEvent(onUsbEvent); // detect USB enumeration, for the status LED
  USBSerial.begin(115200); // USB CDC config port; do NOT wait on it (would stall)
  USB.begin();             // build + start the composite USB device (HID + CDC)
}

void loop() {
  handleSerialConfig(); // apply any pending SET_ID/GET_ID command
  updateStatusLed();    // blink while waiting for USB enumeration, steady once enumerated

  // Push our identity the moment a host opens the CDC port, so the nobs-fs app learns
  // which box it's talking to without sending GET_ID first.
  if (announceIdentity) {
    announceIdentity = false;
    printIdentity("BOOT");
  }

  // Each lever terminal is reported as a held level (pressed = LOW with INPUT_PULLUP).
  for (uint8_t i = 0; i < 6; i++) {
    Joystick.setButton(i, digitalRead(leverPin[i]) == LOW ? 1 : 0);
  }

  // One USB report with all the updates above (sent only when changed).
  Joystick.sendState();

  // Heartbeat: re-publish the current state periodically so a host that opens the
  // device after boot (missing the one initial report) picks up the resting lever
  // positions without the user having to move anything. 250 ms is imperceptible yet
  // negligible USB traffic (1 byte, ~4×/s).
  static uint32_t lastBeat = 0;
  uint32_t now = millis();
  if (now - lastBeat >= 250) {
    lastBeat = now;
    Joystick.resend();
  }
}

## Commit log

2026-06-13 Add models
    [enclosure_bottom.step, enclosure_top.step, nobs_approach_frontpanel.step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]
2026-06-18 Fix heat insert issue
    [enclosure_bottom.step, enclosure_top.step]
2026-06-20 Update models and add wiring diagram
    [enclosure_bottom.step, enclosure_top.step, flaps_lever.step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]
2026-06-20 Update models
    [nobs_approach_mounting_plate.step]
2026-06-20 Finalize flaps lever
    [flaps_lever.step, flaps_lever_bottom.step, flaps_lever_top.step]
2026-06-28 Update frontplate model
    [nobs_approach_frontpanel.step]
2026-06-28 Add bill of materials with estimated project costs
2026-06-28 Add status LED, HID feature report, and unprompted identity push
    Re-pin levers (Flaps inverted), expose resting positions via a Feature
    report plus a 250 ms heartbeat resend, and push board identity as BOOT:...
    on CDC connect. Update wiring and board-identity docs to match, add wiring
    diagram PDF.
    [arduino_eps32_nano.ino]
2026-07-01 Add companion app section, product image, and wiring diagram link to README
2026-07-02 Document rig mounting layout and add assembly image
    Shows how Nobs Panel, Approach, and Autopilot mount together on a
    T-slot rig around the central yoke/wheel assembly.
2026-11-02 Add wiring diagram as SVG and HTML
    The same pins and layout as the existing wiring doc, drawn with each
    control beside the header pins it connects to. The SVG is on a white
    background; the HTML page follows the light/dark theme.
2026-11-02 Add status-LED timeout and USB hand-over fix; ship models as STL
    - Firmware: stop blinking the status LED after 10 s without a host, and
    drop the D+ pull-up briefly before USB.begin() so a cold plug-in
    enumerates the Nobs device instead of the boot-time 303A:1001 one.
    - Models: replace the STEP files with STL, and add the gear lever.
